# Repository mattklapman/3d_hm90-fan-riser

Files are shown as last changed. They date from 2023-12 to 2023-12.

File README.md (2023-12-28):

# hm90-fan-riser
This is a base stand to hold fans under an HM90 Minisforum computer with 1 HDD installed.

The Minisforum HM90 computer has a major flaw with cooling where the lower half of the computer is not cooled with fans nor convection. I am seeing the temperature of my 4TB flash overheat along with the HDD. This riser/stand was built to hold two 40mm fans, each placed to generate airflow in opposite directions to help circulate air to remove heat from the flash heatsink and HDD.

At the time of this creation, commercial cooling units are mostly designed for laptops typically with fans moving air in the same direction.

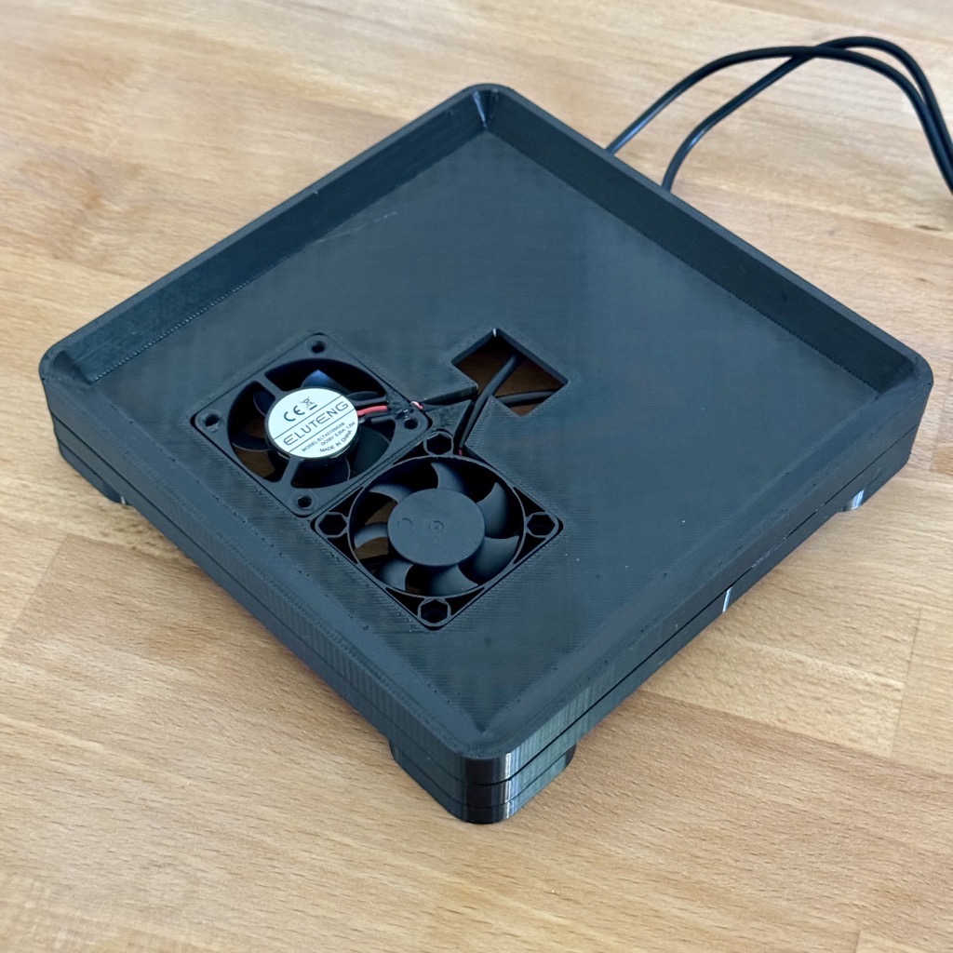
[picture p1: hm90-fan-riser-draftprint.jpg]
hm90fan-riser draft 3D print photo with fans and without HM90 Mini PC


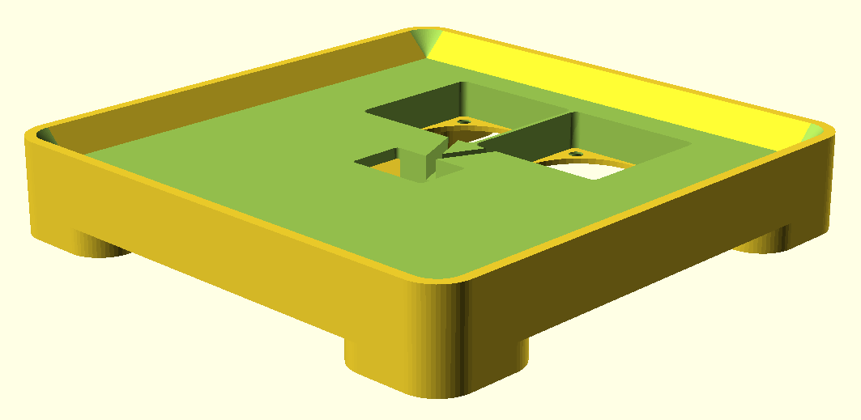
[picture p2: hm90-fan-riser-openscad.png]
hm90-fan-riser OpenSCAD render


## Parts Procured
* USB dual fans with speed control (fan grates removed before utilization):
	* "ELUTENG Dual 40mm USB Fan with 3 Speeds Adjustable 5V PC Fan Max 5500RPM 40mm * 40mm * 25mm Mini Case Fan Quiet Computer Fan Compatible for PC, TV Box, Router, Xbox, Playstation"
	* Amazon link: https://www.amazon.com/dp/B08ZY7X4CR

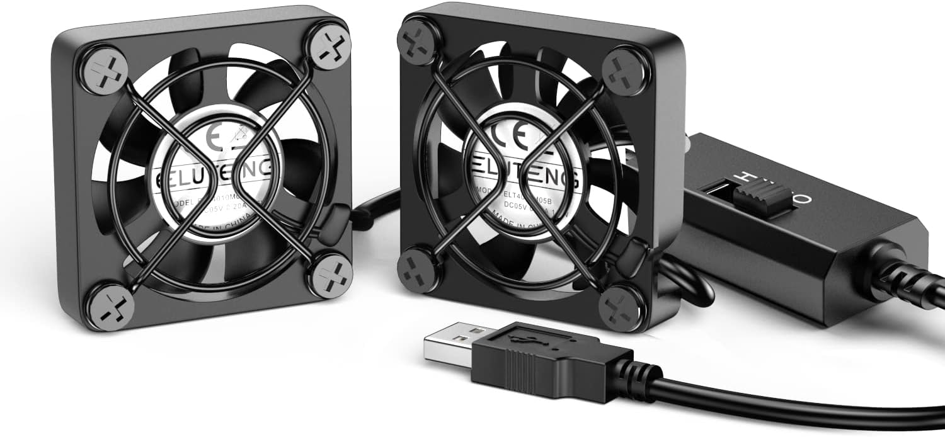
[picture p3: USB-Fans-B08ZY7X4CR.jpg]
ELUTENG dual 40mm USB fan with 3 adjustable speeds


## Design & Assembly Notes
* Print and assemble the layers.
	* There is a pre-cut project file with alignment pegs: `hm90-fan-riser-precut.3mf`
	* Be careful to not let the PETG or other material warp during cooling.
	* Be careful assembling the top two sections to not break the thin wall in between the fans.
* Remove screws and fan grates.
* Feed through the USB wire and control switch through the top center cutout.
* Place fans in opposite directions to maximize air flow throught the hm90 chassis.
* Place HM90 on top (there should be a minimal air gap to maximize the air flow through the HM90 vent).
* Plug in the fans to a USB adapter (or the computer if the computer's power is not overly taxed).

## 3D Printing
Settings used in development:

* 0.4mm nozzle
* PETG (less potential warping from heat compared to PLA)
* 0.28mm layer height
* 15% infill (structural strength, warp reduction, and air gap heat insulating)
* support not required due to slicing

The printing parameters should be flexible for change and provide good results.

## Final Comments
The hm90-fan-riser cooled my NVMe M.2 flash memory by 16°C with the fans high!

There is room for improvement (cable management, USB drive holder, etc.), but you know... 80/20.

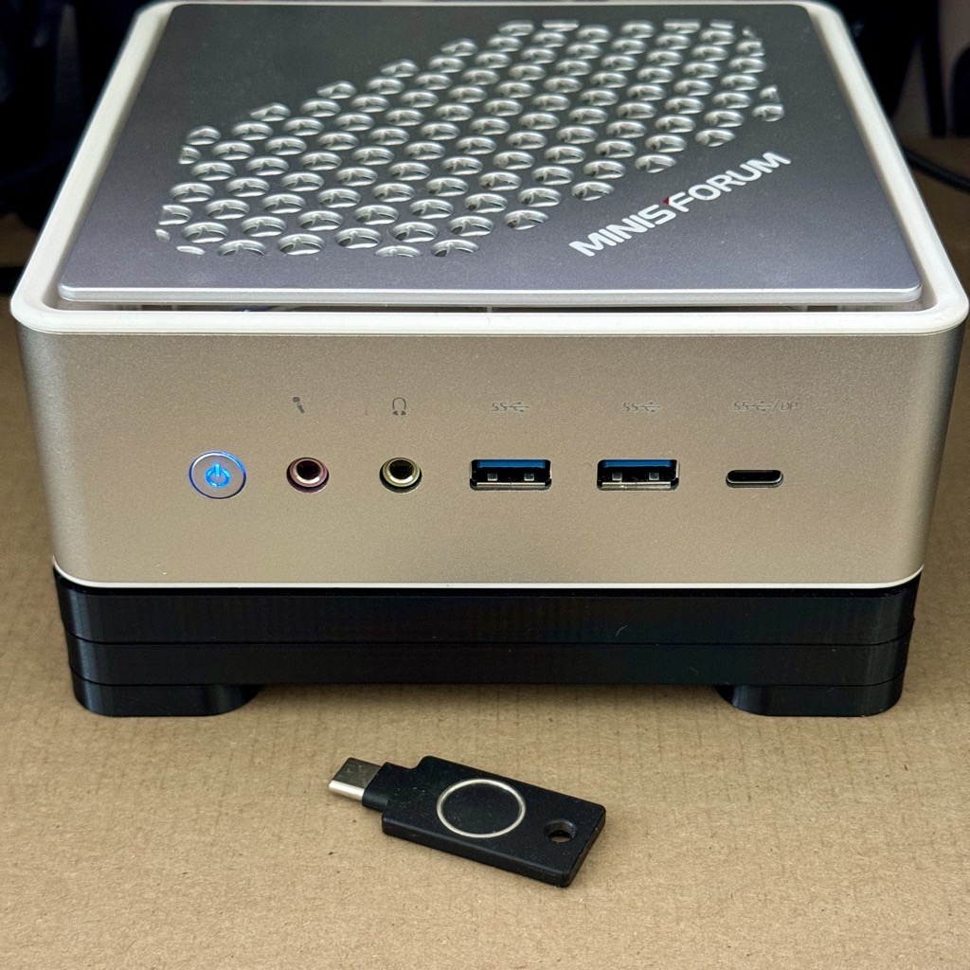
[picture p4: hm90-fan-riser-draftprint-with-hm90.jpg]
hm90-fan-riser draft 3D print photo with HM90 Mini PC


Waiting for 3D prints is the new waiting for downloads over a 56K baud modem. Just saying.

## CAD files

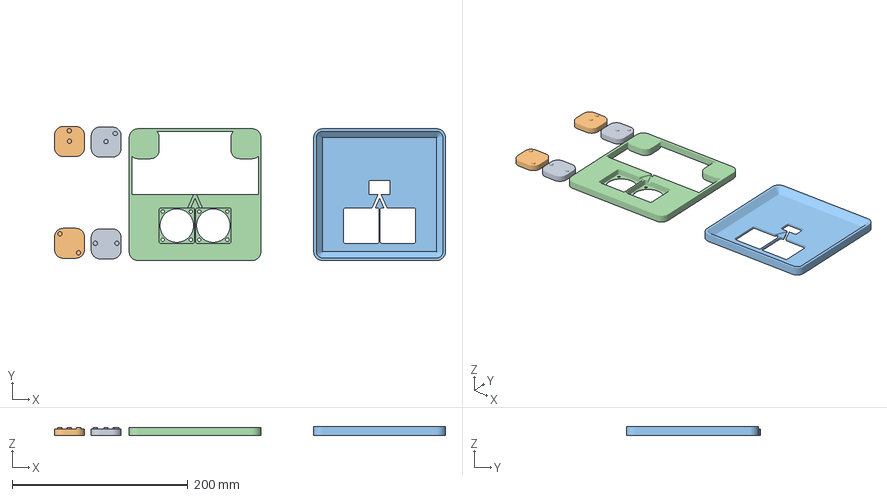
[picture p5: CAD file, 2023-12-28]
hm90-fan-riser-precut.3mf
444.4 x 152.3 x 10.0 mm
OpenSCAD Model_B_A
OpenSCAD Model_B_B
OpenSCAD Model_A_A
OpenSCAD Model_A_B

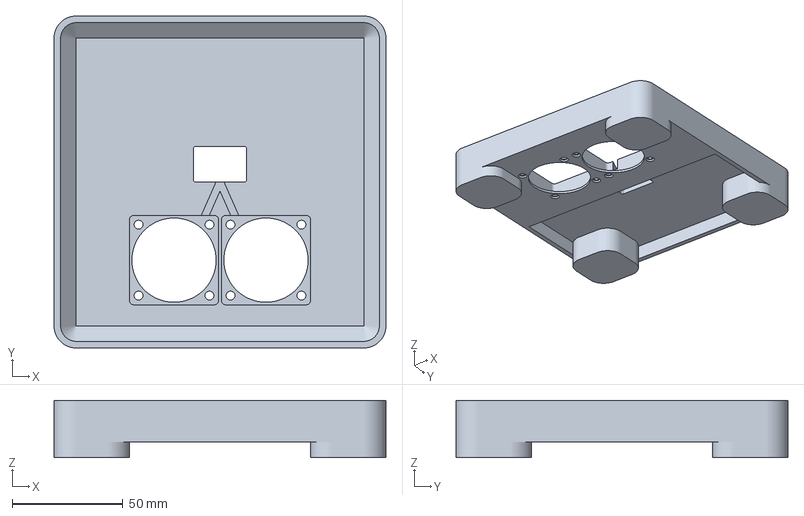
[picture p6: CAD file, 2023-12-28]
hm90-fan-riser.3mf
149.8 x 149.8 x 25.8 mm

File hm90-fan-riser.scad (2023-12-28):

// HM90 Fan Riser: holds two fans (40mm x 25mm) to cool the lower inside of an HM90 Mini PC
// OpenSCAD units are millimeters

/****************
BSD 2-Clause License

Copyright (c) 2023, mattklapman

Redistribution and use in source and binary forms, with or without
modification, are permitted provided that the following conditions are met:

1. Redistributions of source code must retain the above copyright notice, this
   list of conditions and the following disclaimer.

2. Redistributions in binary form must reproduce the above copyright notice,
   this list of conditions and the following disclaimer in the documentation
   and/or other materials provided with the distribution.

THIS SOFTWARE IS PROVIDED BY THE COPYRIGHT HOLDERS AND CONTRIBUTORS "AS IS"
AND ANY EXPRESS OR IMPLIED WARRANTIES, INCLUDING, BUT NOT LIMITED TO, THE
IMPLIED WARRANTIES OF MERCHANTABILITY AND FITNESS FOR A PARTICULAR PURPOSE ARE
DISCLAIMED. IN NO EVENT SHALL THE COPYRIGHT HOLDER OR CONTRIBUTORS BE LIABLE
FOR ANY DIRECT, INDIRECT, INCIDENTAL, SPECIAL, EXEMPLARY, OR CONSEQUENTIAL
DAMAGES (INCLUDING, BUT NOT LIMITED TO, PROCUREMENT OF SUBSTITUTE GOODS OR
SERVICES; LOSS OF USE, DATA, OR PROFITS; OR BUSINESS INTERRUPTION) HOWEVER
CAUSED AND ON ANY THEORY OF LIABILITY, WHETHER IN CONTRACT, STRICT LIABILITY,
OR TORT (INCLUDING NEGLIGENCE OR OTHERWISE) ARISING IN ANY WAY OUT OF THE USE
OF THIS SOFTWARE, EVEN IF ADVISED OF THE POSSIBILITY OF SUCH DAMAGE.
*****************/

include <Chamfers-for-OpenSCAD/Chamfer.scad>;

wallThickness = 3; // used for the tray bottom; thick enough to have an internal truss to reduce warping over time (15% infill)
wallThicknessMin = 1.5;

clearance = 0.3; // allow some space as 3D printing isn't perfect

// from a horizontal view looking at the front
hm90Width = 149.5 + clearance;  // measurement left to right
hm90Length = 149.5 + clearance; // measurement front to back
hm90Height = 50 + 3.5 + clearance; // with feet
hm90Radial = 10; // corners (eyeballed)

hm90VentWidth = 75.5;
hm90VentLength = 45.3; // through holes are actually smaller
hm90VentOffset = 17; // from front to start of length

fanWidth = 40;
fanLength = 40;
fanHeight = 10.3; // does not include any wireframe around it
fanCableDiameter = 3;
fanCableOffset = 6; // short distance of outside cable to edge of fan

// fan dongle must pass through hole
fanCablePassthroughX = 23.1 + 1;
fanCablePassthroughY = 15 + 1;

standRadial = hm90Radial;
hm90shelf = 3.5 + 1 + 2.5; // depth of hm90 into the base
bottomAirGap = 7; // height off of the desk to allow airflow

$fn=60; // number of resolved facets on curves
renderHelp = 0.001; // used during development to correct visual artifacts in OpenSCAD (OK to print with this)

module tray()
{
    difference()
    {
        // tray
        translate([0, 0, bottomAirGap + wallThicknessMin + fanHeight - wallThickness + (hm90shelf + wallThickness)/2]) cubeRadial(hm90Width, hm90Length, (hm90shelf + wallThickness), standRadial, 1);
        union()
        {
            // tray inset
            translate([0, 0, bottomAirGap + wallThicknessMin + fanHeight + hm90Height/2]) cubeChamferRoundTopBot(hm90Width, hm90Length, hm90Height, hm90Radial);
            
            // vent(s)
            translate([0, 0, 0.014]) fans(); // I do not know why there is a 0.014mm error here
            fans();
            
        }
    }
}

module fanSupport()
{
    // outside skirt
    difference()
        {
            translate([0, 0, bottomAirGap + (fanHeight + wallThicknessMin - wallThickness)/2]) cubeRadial(hm90Width, hm90Length, fanHeight + wallThicknessMin - wallThickness, standRadial, 1);
            translate([0, 0, bottomAirGap + (fanHeight + wallThicknessMin - wallThickness)/2]) cubeRadial(hm90Width - 2*wallThickness, hm90Length - 2*wallThickness, fanHeight + wallThicknessMin - wallThickness + 2*renderHelp, standRadial, 1);
        }
    
    // fan cavity
    difference()
    {
        union()
        {
            translate([0, -hm90Length/4, bottomAirGap + (fanHeight + wallThicknessMin - wallThickness)/2]) cubeRadial(hm90Width, hm90Length/2, fanHeight + wallThicknessMin - wallThickness, standRadial, 1);
            // clean up the inner rounded corners
            translate([0, -hm90Length/8, bottomAirGap + (fanHeight + wallThicknessMin - wallThickness)/2]) cube([hm90Width, hm90Length/4, fanHeight + wallThicknessMin - wallThickness], center=true);
        }
        union()
        {
            fans();
            translate([0, 0, -wallThicknessMin]) fans();
        }
    }
}

module fanMounts()
{
    translate([-(wallThicknessMin/2 + fanWidth/2), -hm90Length/2 + hm90VentOffset + hm90VentLength/2, bottomAirGap + wallThicknessMin/2])
        fanMountCorners();
    translate([(wallThicknessMin/2 + fanWidth/2), -hm90Length/2 + hm90VentOffset + hm90VentLength/2, bottomAirGap + wallThicknessMin/2])
        fanMountCorners();
}
module fanMountCorners()
{
    difference()
    {
        // corner shelves
        linear_extrude(height=wallThicknessMin, center=true)
            difference()
            {
                square([fanWidth + clearance, fanLength + clearance], center=true);
                circle(d=38);
            }
        // holes
        translate([(fanWidth/2 - 4), (fanLength/2 - 4), 0]) cylinder(h=2*wallThicknessMin, d=4, center=true);
        translate([(fanWidth/2 - 4), -(fanLength/2 - 4), 0]) cylinder(h=2*wallThicknessMin, d=4, center=true);
        translate([-(fanWidth/2 - 4), (fanLength/2 - 4), 0]) cylinder(h=2*wallThicknessMin, d=4, center=true);
        translate([-(fanWidth/2 - 4), -(fanLength/2 - 4), 0]) cylinder(h=2*wallThicknessMin, d=4, center=true);

        // countersinks
        translate([(fanWidth/2 - 4), (fanLength/2 - 4), -wallThicknessMin/2]) cylinder(h=2, d1=6.6, d2=4, center=true);
        translate([(fanWidth/2 - 4), -(fanLength/2 - 4), -wallThicknessMin/2]) cylinder(h=2, d1=6.6, d2=4, center=true);
        translate([-(fanWidth/2 - 4), (fanLength/2 - 4), -wallThicknessMin/2]) cylinder(h=2, d1=6.6, d2=4, center=true);
        translate([-(fanWidth/2 - 4), -(fanLength/2 - 4), -wallThicknessMin/2]) cylinder(h=2, d1=6.6, d2=4, center=true);        
    }
}

module feet()
{
    // corner cube stands
    standCornerWidth = (hm90Width - max(hm90VentWidth, 2*fanWidth + wallThicknessMin))/2;
    standCenterWidth = 2*(hm90Length/2 - hm90VentOffset - hm90VentLength);
    // center circle stand
    translate([-(hm90Width/2 - standCornerWidth/2), -(hm90Width/2 - standCornerWidth/2), bottomAirGap/2])
        cubeRadial(standCornerWidth, standCornerWidth, bottomAirGap, standRadial, 1);
    translate([-(hm90Width/2 - standCornerWidth/2), (hm90Width/2 - standCornerWidth/2), (bottomAirGap + wallThicknessMin + fanHeight - wallThickness)/2])
        cubeRadial(standCornerWidth, standCornerWidth, bottomAirGap + wallThicknessMin + fanHeight - wallThickness, standRadial, 1);
    translate([(hm90Width/2 - standCornerWidth/2), -(hm90Width/2 - standCornerWidth/2), bottomAirGap/2])
        cubeRadial(standCornerWidth, standCornerWidth, bottomAirGap, standRadial, 1);
    translate([(hm90Width/2 - standCornerWidth/2), (hm90Width/2 - standCornerWidth/2), (bottomAirGap + wallThicknessMin + fanHeight - wallThickness)/2])
        cubeRadial(standCornerWidth, standCornerWidth, bottomAirGap + wallThicknessMin + fanHeight - wallThickness, standRadial, 1);
}

module fans()
{
    translate([-wallThicknessMin/2 - fanWidth/2, -hm90Length/2 + hm90VentOffset + hm90VentLength/2, bottomAirGap + wallThicknessMin + fanHeight/2]) cubeRadial(fanWidth + clearance, fanLength + clearance, fanHeight + 2*renderHelp, 2, 1);
    translate([+wallThicknessMin/2 + fanWidth/2, -hm90Length/2 + hm90VentOffset + hm90VentLength/2, bottomAirGap + wallThicknessMin + fanHeight/2]) cubeRadial(fanWidth + clearance, fanLength + clearance, fanHeight + 2*renderHelp, 2, 1);
}

/****************
// Main
*****************/
// difference is to create the fan cable rounting
difference()
{
    union()
    {
        tray();
        color("red") fanSupport();
        fanMounts();
        feet();
    }
    // cable dongle hole
    translate([0, fanCablePassthroughY/2, 0]) cubeRadial(fanCablePassthroughX, fanCablePassthroughY, hm90Height, 1, 1);
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

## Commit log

2023-12-26 added initial design and submodule
    [hm90-fan-riser.3mf, hm90-fan-riser.scad]
2023-12-26 fixed source code submodule include
    [hm90-fan-riser.scad]
2023-12-28 added fanGrates to match procured fans; adjusted to fan parameters
    [hm90-fan-riser.scad]
2023-12-28 cleaned up errors; removed inner curve; added sliced print project
    [hm90-fan-riser-sliced.3mf, hm90-fan-riser.3mf, hm90-fan-riser.scad]
2023-12-28 fixed parameter warning
    [hm90-fan-riser.scad]
2023-12-28 removed fanGrates; added slice instructions; fixed some overlaps; created new slice project
    [hm90-fan-riser-sliced.3mf, hm90-fan-riser.3mf, hm90-fan-riser.scad]
2023-12-28 changed slicing dowels to plugs to simplify
    [hm90-fan-riser-sliced.3mf]
2023-12-28 updated README.md with a few images; renamed hm90-fan-riser-precut.3mf; cleaned up source code and added license in source
    [hm90-fan-riser-precut.3mf, hm90-fan-riser.scad]
